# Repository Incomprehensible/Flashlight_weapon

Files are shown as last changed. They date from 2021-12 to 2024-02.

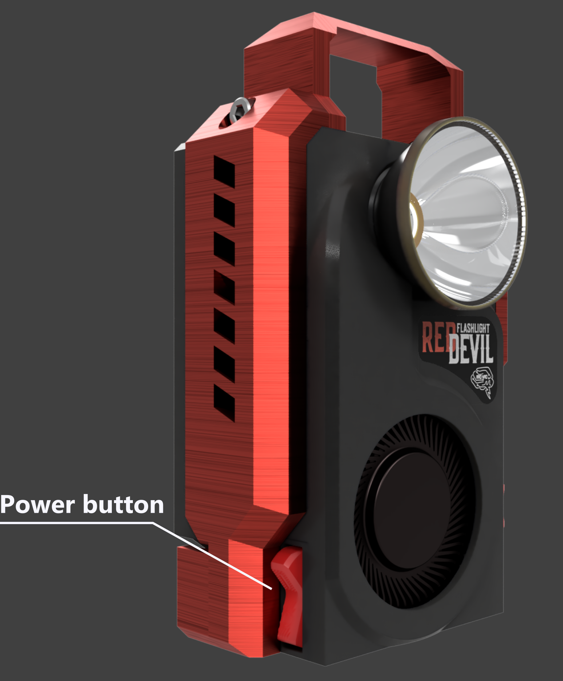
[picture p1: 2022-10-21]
Renders&Graphics/21_NAD_flashlight_2_EDIT_3_explanation.png

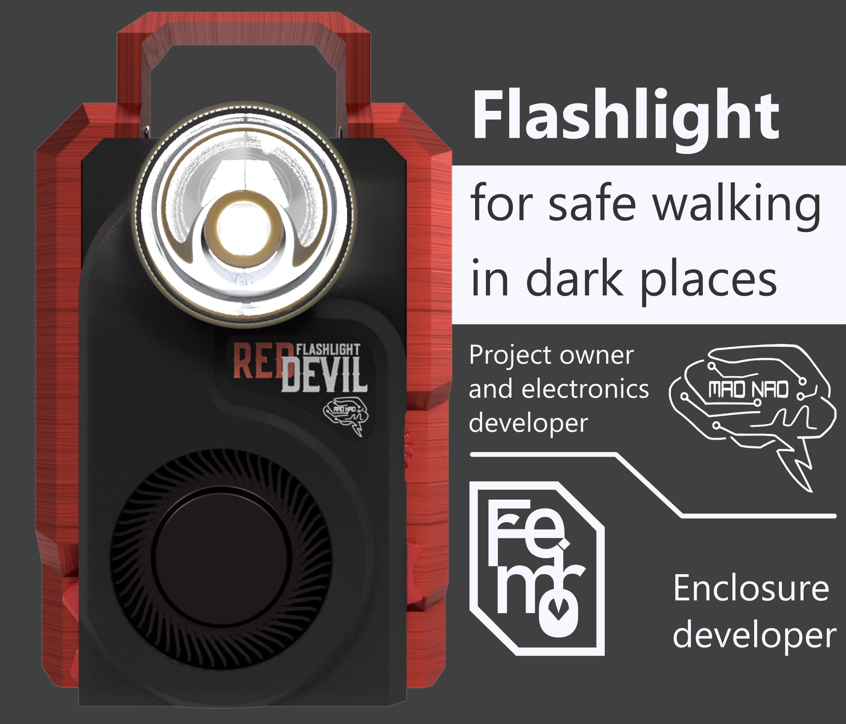
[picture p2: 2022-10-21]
Renders&Graphics/21_NAD_flashlight_2_EDIT_1_explanation.png

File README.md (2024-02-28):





## Flashlight features
__Two operation modes toggled by selector__

 * Normal light: regular use

 * Emergency mode: blinding light attack

__Variable light intensity, changable with a knob__

__Interchangeable lens__

__Mount for action camera accessories__
<br/><br/>
<br/><br/>
<br/><br/>
<br/><br/>
 

### Electrical characteristics
* 12.6V - 10.5V input
* ~4.5A input
* 7V output
* 7.5A output
<br/><br/>
<br/><br/>
<br/><br/>
<br/><br/>
## PCB design

Top             |  Bottom
:-------------------------:|:-------------------------:
  |  
 | 

#### Further improvement in design:
* Add a latching circuit with bistable relay to avoid losing power in emergency mode.
* Add suitable input power filtering.

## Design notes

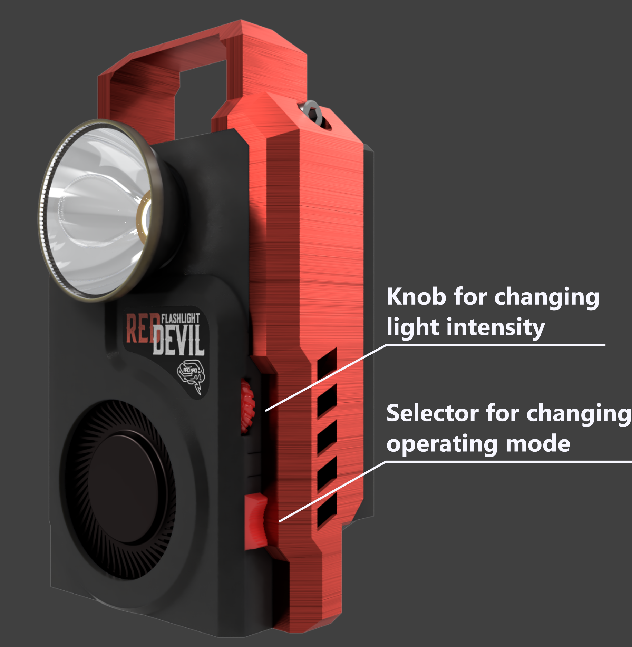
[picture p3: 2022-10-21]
Renders&Graphics/21_NAD_flashlight_2_EDIT_2_explanation.png

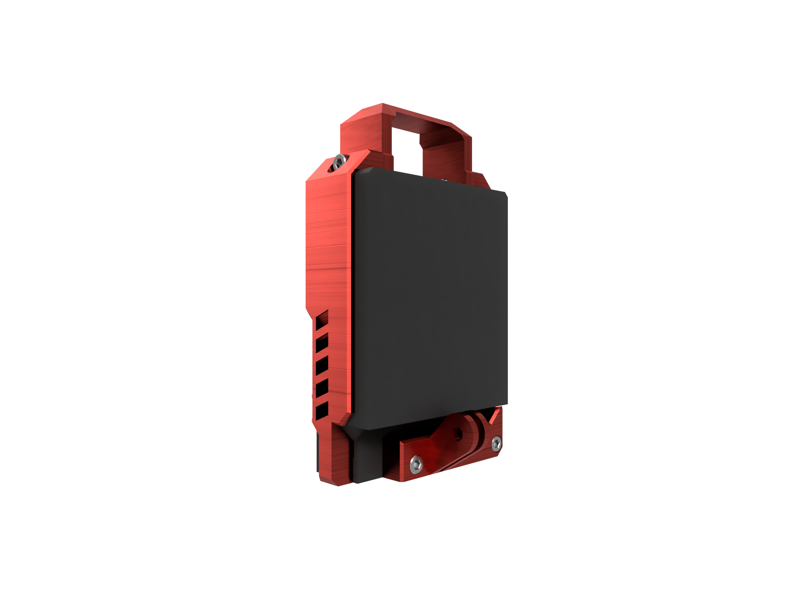
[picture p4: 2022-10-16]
Renders&Graphics/21_NAD_flashlight_front_8.png

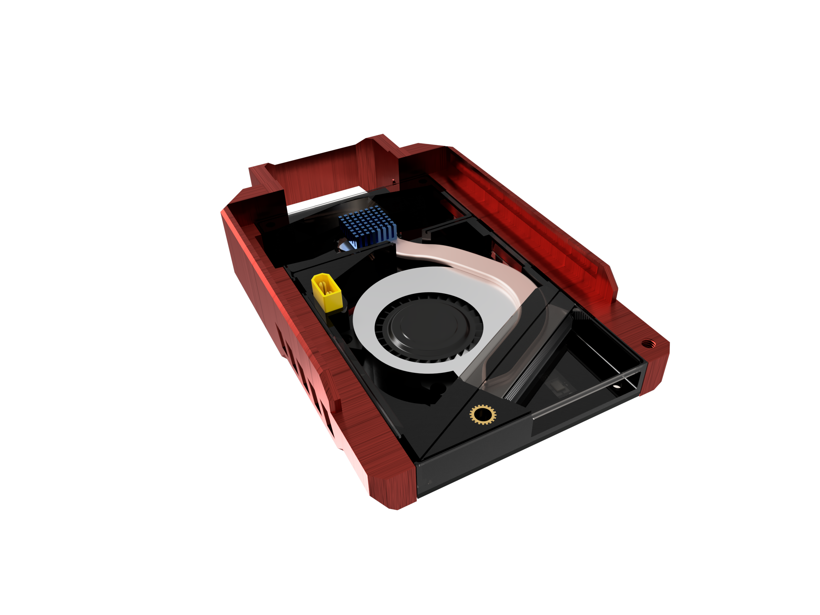
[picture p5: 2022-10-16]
Renders&Graphics/21_NAD_flashlight_front_19.PNG

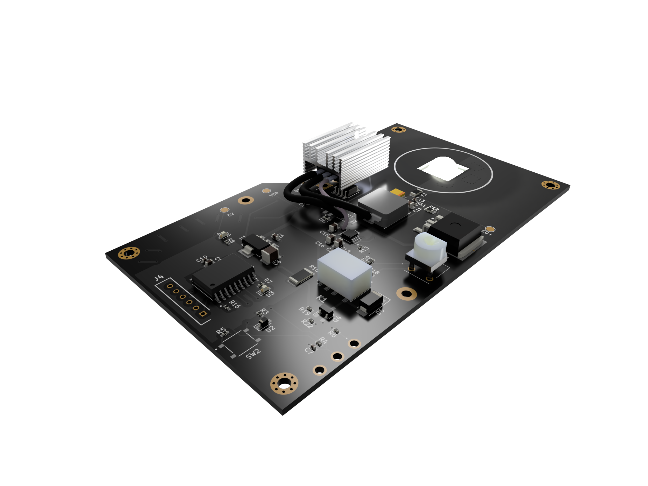
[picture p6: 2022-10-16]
Renders&Graphics/21_NAD_flashlight_front_20.PNG

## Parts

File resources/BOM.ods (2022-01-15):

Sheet: Roster
Flashlight |  |  |  |  |  |  | 2021
TEAM NAD
# | Component | Name | Qua-ty | Link | Price | Datasheet | Notes
1 | Cvin | GRM21BR61E106MA73L | 2 | https://www.chipdip.ru/product0/8001940268 | 130 * 2 | https://search.murata.co.jp/Ceramy/image/img/A01X/G101/ENG/GRM21BR61E106MA73-01.pdf | 10uF 0805
2 | Rt | CRCW040260K4FKED | 1 | https://lcsc.com/product-detail/Chip-Resistor-Surface-Mount_Vishay-Intertech-CRCW040260K4FKED_C844314.html | 25 | https://www.vishay.com/docs/20035/dcrcwe3.pdf | 60.4k 0402
3 | Cvcc | TMK212BJ474KD-T | 1 | https://lcsc.com/product-detail/Multilayer-Ceramic-Capacitors-MLCC-SMD-SMT_Taiyo-Yuden-TMK212BJ474KD-T_C386088.html | 2*20 | https://ru.mouser.com/datasheet/2/396/mlcc02_e-1307760.pdf | 470nF 0805
4 | Cadj | CL05C102JB5NNNC | 1 | https://lcsc.com/product-detail/Multilayer-Ceramic-Capacitors-MLCC-SMD-SMT_Samsung-Electro-Mechanics-CL05C102JB5NNNC_C307441.html | 0.6*50 | https://datasheet.lcsc.com/lcsc/1810310921_Samsung-Electro-Mechanics-CL05C102JB5NNNC_C307441.pdf | 1nF 0402
5 | Radj | CRCW04023K16FKED | 1 | https://www.chipdip.ru/product0/8008399175 | 130 | https://www.vishay.com/docs/20035/dcrcwe3.pdf | 3.16k 0402
 |  | CR0603-FX-3161ELF | 1 | https://lcsc.com/product-detail/Chip-Resistor-Surface-Mount_BOURNS-CR0603-FX-3161ELF_C203516.html | 6 |  | 3.16k 0603
 |  | 0603WAF2941T5E | 1 | https://lcsc.com/product-detail/Chip-Resistor-Surface-Mount_UNI-ROYAL-Uniroyal-Elec-0603WAF2941T5E_C22909.html | 11 |  | 2.94k 0603
6 | Rsns | RL3720WT-R010-F | 1 | https://www.chipdip.ru/product/rl3720wt-r010-f | 92 | https://static.chipdip.ru/lib/677/DOC011677925.pdf | 0.01 1508
 |  | RL3720WT-R010-FNH | 1 | https://lcsc.com/product-detail/Chip-Resistor-Surface-Mount_Cyntec-RL3720WT-R010-FNH_C367339.html | 27 | https://datasheet.lcsc.com/lcsc/1912111437_Cyntec-RL3720WT-R010-FNH_C367339.pdf | 0.01 1W SMD 1508
7 | Q2 PMOS driver | CSD25402Q3A | 1 | https://lcsc.com/product-detail/MOSFETs_Texas-Instruments-CSD25402Q3A_C111356.html | 100 | https://www.ti.com/lit/ds/symlink/csd25402q3a.pdf
8 | D Schottky | MBRB4030T4G | 1 | https://www.chipdip.ru/product/mbrb4030t4g-schottky-diode-40a-30v-sw | 480 | https://static.chipdip.ru/lib/550/DOC012550016.pdf | too expensive
9 | Inductor | IHLP4040DZER2R2M01 | 1 | https://lcsc.com/product-detail/Power-Inductors_Vishay-Intertech-IHLP4040DZER2R2M01_C499483.html | 104 | https://datasheet.lcsc.com/lcsc/2003271205_Vishay-Intertech-IHLP4040DZER2R2M01_C499483.pdf | alternative: IHLP5050CEER2R2M01
10 | Cff | GRM2165C2A202JA01D | 1 | https://lcsc.com/product-detail/Multilayer-Ceramic-Capacitors-MLCC-SMD-SMT_Murata-Electronics-GRM2165C2A202JA01D_C710939.html | 2*20 | https://datasheet.lcsc.com/lcsc/2103161034_Murata-Electronics-GRM2165C2A202JA01D_C710939.pdf | 2nF 0805
11 | Rfb2 | RC0201FR-0710KL | 1 | https://lcsc.com/product-detail/Chip-Resistor-Surface-Mount_YAGEO-RC0201FR-0710KL_C106225.html | 8 | https://datasheet.lcsc.com/lcsc/1811101938_YAGEO-RC0201FR-0710KL_C106225.pdf | 10k 0201
12 | Rfb1 | RT0805BRD072K18L | 1 | https://www.digikey.be/product-detail/en/yageo/RT0805BRD072K18L/13-RT0805BRD072K18LCT-ND/12704381 | 0.3 dollars |  | 2.18k 0805
13 | Cout tantalum | 10TPE47MAZB | 1 | https://lcsc.com/product-detail/Tantalum-Capacitors_PANASONIC-10TPE47MAZB_C147768.html | 45 | https://datasheet.lcsc.com/lcsc/1810120928_PANASONIC-10TPE47MAZB_C147768.pdf | 47uF CASE-B_3528
14 | Rparallel | CR0603F3K00P05Z | 1 | https://lcsc.com/product-detail/Chip-Resistor-Surface-Mount_Ever-Ohms-Tech-CR0603F3K00P05Z_C881244.html | 14 |  | 3k 0603 100mW
 |  | 0603WAF3091T5E | 1 | https://lcsc.com/product-detail/Chip-Resistor-Surface-Mount_UNI-ROYAL-Uniroyal-Elec-0603WAF3091T5E_C22992.html | 10 |  | 3.1k 0603 100mW
 |  | WR06X1501FTL | 1 | https://lcsc.com/product-detail/Chip-Resistor-Surface-Mount_Walsin-Tech-Corp-WR06X1501FTL_C163839.html | 7 |  | 1.5k 0603 100mW
 |  | RTT03102JTP | 1 | https://lcsc.com/product-detail/Chip-Resistor-Surface-Mount_RALEC-RTT03102JTP_C103209.html | 8 |  | 1k 0603 100mW
15 | Rcushion | TyoHM SMF 3W 10R J | 1 | https://lcsc.com/product-detail/Chip-Resistor-Surface-Mount_TyoHM-SMF-3W-10R-J_C395115.html | 3 |  | 10Ω SMD 3W
 |  | TyoHM SMF 3W 100R J | 1 | https://lcsc.com/product-detail/Chip-Resistor-Surface-Mount_TyoHM-SMF-3W-100R-J_C395118.html | 4 |  | 100Ω SMD 3W
16 | Rvariable | VZ067TL1B303 | 1 | https://lcsc.com/product-detail/Variable-Resistors-Potentiometers_HDK-Hokuriku-Elec-Industry-VZ067TL1B303_C145139.html | 33 | https://datasheet.lcsc.com/lcsc/1810170429_HDK-Hokuriku-Elec-Industry-VZ067TL1B303_C145139.pdf | 30k 0.1W
17 | Mode switch | SS-12D06L5 | 1 | https://lcsc.com/product-detail/Slide-Switches_XKB-Connectivity-SS-12D06L5_C319015.html | 22 | https://datasheet.lcsc.com/lcsc/2110151630_XKB-Connectivity-SS-12D06L5_C319015.pdf | SPDT 250V 3A
18 | Relay | HFD4/24-SR | 1 | https://lcsc.com/product-detail/Signal-Relays_HF-Xiamen-Hongfa-Electroacoustic-HFD4-24-SR_C390665.html | 150 | https://datasheet.lcsc.com/lcsc/1912111437_HF-Xiamen-Hongfa-Electroacoustic-HFD4-24-SR_C390665.pdf | SPDT 24V DC 2A non-blocking
19 | MCU | PIC16F716-I/SO | 1 | https://www.chipdip.ru/product/pic16f716-i-so | 56 | https://static.chipdip.ru/lib/046/DOC003046591.pdf | SOIC
20 | DC-DC | AMS1117-5.0 | 1 | https://lcsc.com/product-detail/Linear-Voltage-Regulators-LDO_HGC-Huaguan-Semicon-AMS1117-5-0_C498116.html | 7*5 | https://datasheet.lcsc.com/lcsc/2005291002_HGC-Huaguan-Semicon-AMS1117-5-0_C498116.pdf | 5V SOT223
21 | Crystal | X1E0003410031 | 1 | https://lcsc.com/product-detail/Crystals_Seiko-Epson-X1E0003410031_C725712.html | 35 | https://datasheet.lcsc.com/lcsc/2008192035_Seiko-Epson-X1E0003410031_C725712.pdf | -40℃~+125℃ SMD3225-4P
22 | Power connector | XT60PW-F | 1 | https://www.chipdip.ru/product/xt60pw-f | 320
 |  | XT30PW-F | 1 |  |  |  | bought on aliexpress
23 | Temp sensor | LM60BIM3 | 1 | https://www.chipdip.ru/product0/8002949797 | 280 | https://static.chipdip.ru/lib/053/DOC006053227.pdf | SOT-23
24 | Schottky 12V | 1N5819WS | 1 | https://lcsc.com/product-detail/Schottky-Barrier-Diodes-SBD_Guangdong-Hottech-1N5819WS_C191023.html | 44 | https://datasheet.lcsc.com/lcsc/1810202112_Guangdong-Hottech-1N5819WS_C191023.pdf | 40V SOD-323
25 | Power fuse | 121108 | 1 | https://lcsc.com/product-detail/Fuses_TLC-Electronic-121108_C364828.html | 32 | https://datasheet.lcsc.com/lcsc/1912111437_TLC-Electronic-121108_C364828.pdf | Delay 8A 123mV 24V 10mΩ 1206
 |  | 12T.70000032AG12S1B02 | 1 | https://lcsc.com/product-detail/Fuses_Xucheng-Elec-12T-70000032AG12S1B02_C140481.html | 27 | https://datasheet.lcsc.com/lcsc/1809211025_Xucheng-Elec-12T-70000032AG12S1B02_C140481.pdf | Delay 7A 1206 32V
 |  | 12T.00100024AG12S1B02 | 1 | https://lcsc.com/product-detail/Fuses_Xucheng-Elec-12T-00100024AG12S1B02_C140482.html | 32 | https://datasheet.lcsc.com/lcsc/1809211025_Xucheng-Elec-12T-00100024AG12S1B02_C140482.pdf | Delay 10A 1206
 |  | 0458010.DR | 1 | https://lcsc.com/product-detail/Fuses_Littelfuse-0458010-DR_C187564.html | 25 | https://datasheet.lcsc.com/lcsc/1810111822_Littelfuse-0458010-DR_C187564.pdf | Fast 10A 1206
26 | LED fuse | 1211012 | 1 | https://lcsc.com/product-detail/Fuses_TLC-Electronic-1211012_C364830.html | 20 | https://datasheet.lcsc.com/lcsc/1912111437_TLC-Electronic-1211012_C364830.pdf | Delay 12A 24V 5mΩ 1206
 |  | 1211015 | 1 | https://lcsc.com/product-detail/Fuses_TLC-Electronic-1211015_C364831.html | 31 |  | Delay 15A 3.5mΩ 1206
 |  | 0501020.WR | 1 | https://lcsc.com/product-detail/Fuses_Littelfuse-0501020-WR_C371157.html | 17 | https://datasheet.lcsc.com/lcsc/1912111437_Littelfuse-0501020-WR_C371157.pdf | Fast 20A 32V 58.88mV 1206
27 | TVS D | SDC15.TCT | 1 | https://lcsc.com/product-detail/span-style-background-color-ff0-TVS-span_SEMTECH-SDC15-TCT_C441849.html | 22 | https://datasheet.lcsc.com/lcsc/2004021403_SEMTECH-SDC15-TCT_C441849.pdf | 10A BR=14.3V 12.8V 7Inch
28 | Q1 PMOS Vin | YJS4407A | 1 | https://lcsc.com/product-detail/MOSFETs_Yangzhou-Yangjie-Elec-Tech-YJS4407A_C919398.html | 47 | https://www.21yangjie.com/ggs/mosfet/zdymosfet/YJS4407A.pdf | P-channel 30V 12A 10.5mΩ
29 | ICSP header | B6B-EH-A | 1 | https://www.chipdip.ru/product/b6b-eh-a | 37 | https://static.chipdip.ru/lib/060/DOC000060471.pdf | 6 pin JST
30 | TH2 NTC | NCP18XW223J03RB | 1 | https://lcsc.com/product-detail/NTC-Thermistors_Murata-Electronics-NCP18XW223J03RB_C86144.html | 44 | https://datasheet.lcsc.com/lcsc/1810311126_Murata-Electronics-NCP18XW223J03RB_C86144.pdf | 22kΩ 100mW 0603
 |  | ERTJ1VR333J | 1 | https://lcsc.com/product-detail/NTC-Thermistors_PANASONIC-ERTJ1VR333J_C153017.html | 25 | https://lcsc.com/product-detail/NTC-Thermistors_PANASONIC-ERTJ1VR333J_C153017.html | 33kΩ 100mW 0603
31 | Q3 NMOS | YJL2302B | 1 | https://lcsc.com/product-detail/MOSFETs_Yangzhou-Yangjie-Elec-Tech-YJL2302B_C699316.html | 35 | https://datasheet.lcsc.com/lcsc/2007231239_Yangzhou-Yangjie-Elec-Tech-YJL2302B_C699316.pdf | 20V 3A SOT-23-3L SOT-23-3L
32 | Q4 NMOS | YJL2302B | 1 | https://lcsc.com/product-detail/MOSFETs_Yangzhou-Yangjie-Elec-Tech-YJL2302B_C699316.html |  | https://datasheet.lcsc.com/lcsc/2007231239_Yangzhou-Yangjie-Elec-Tech-YJL2302B_C699316.pdf | SOT-23-3L
33 | Flyback D | HD20G | 1 | https://lcsc.com/product-detail/Diodes-General-Purpose_High-span-style-background-color-ff0-Diode-span-HD20G_C466497.html | 3*10 | https://datasheet.lcsc.com/lcsc/1912111437_High-Diode-HD20G_C466497.pdf | 2kV 1A SMAG

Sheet: Schedule
Team Name |  |  |  |  |  | 2016
SCHEDULE
Date | Day | Time | Location | Opponent | Home/Away | Notes | Score
Sep 4 | Monday | 1:00 PM | Park A - Field #1 | Team 2 | Home |  | 1-1
 | Saturday
 | Saturday
 | Saturday
 | Saturday
 | Saturday
 | Saturday
 | Saturday
 | Saturday
 | Saturday
 | Saturday
 | Saturday
 | Saturday
 | Saturday
 | Saturday

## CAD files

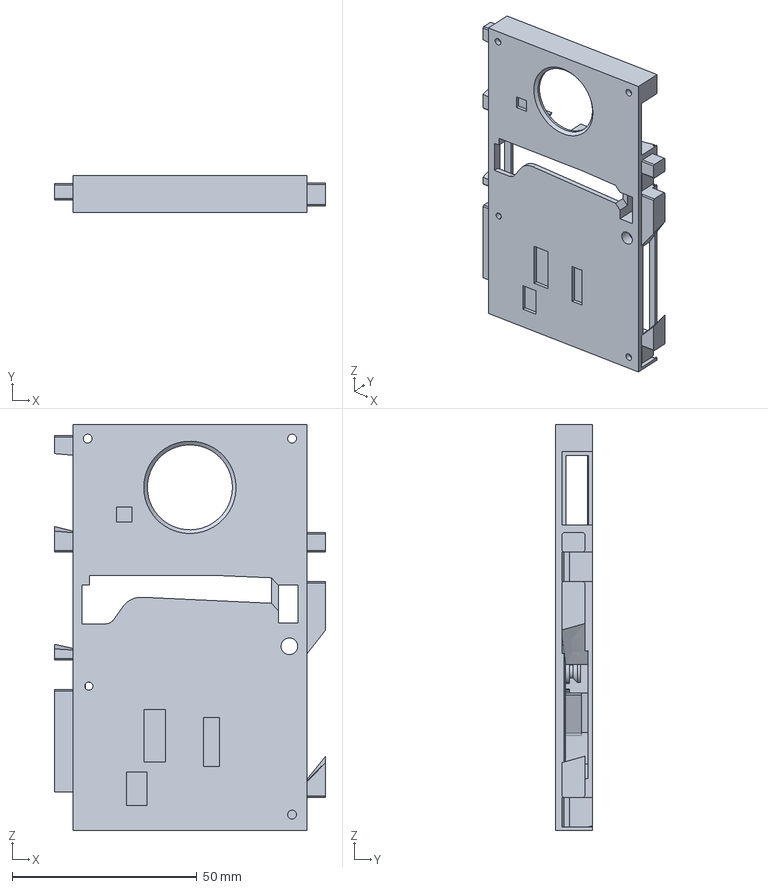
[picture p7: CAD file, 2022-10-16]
3D_models/Files_for_production/2LVL_base_Heat-ResistantPhotopolymer.step
73.5 x 10.1 x 110.0 mm

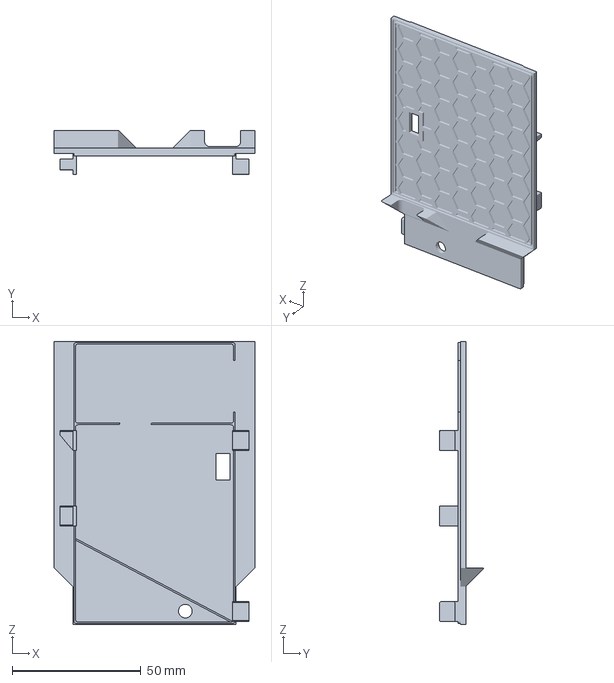
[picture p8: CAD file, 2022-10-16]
3D_models/Files_for_prototype/2LVL_face_PETG.3mf
78.0 x 17.3 x 110.0 mm

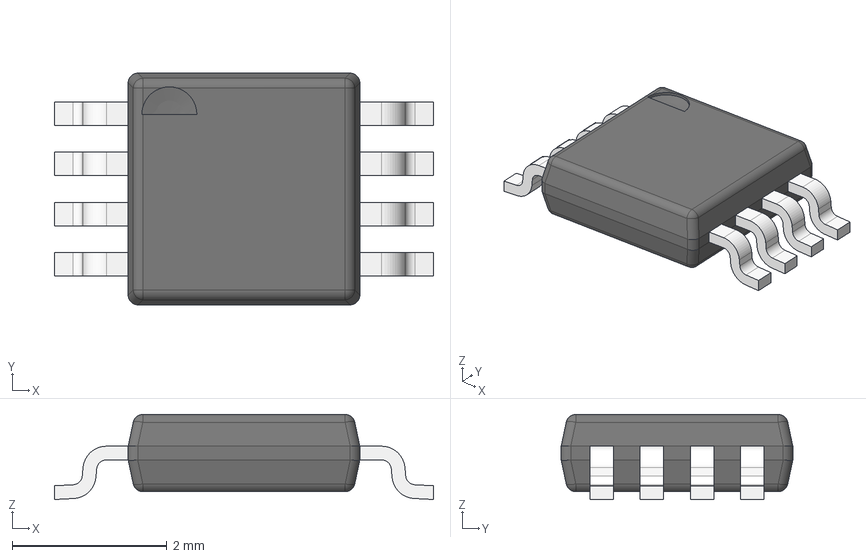
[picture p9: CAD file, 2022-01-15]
KiCad/3D/DGK0008A.stp
4.90 x 3.00 x 1.10 mm
BODY_MUA08A
LEAD_MUA08A x 8

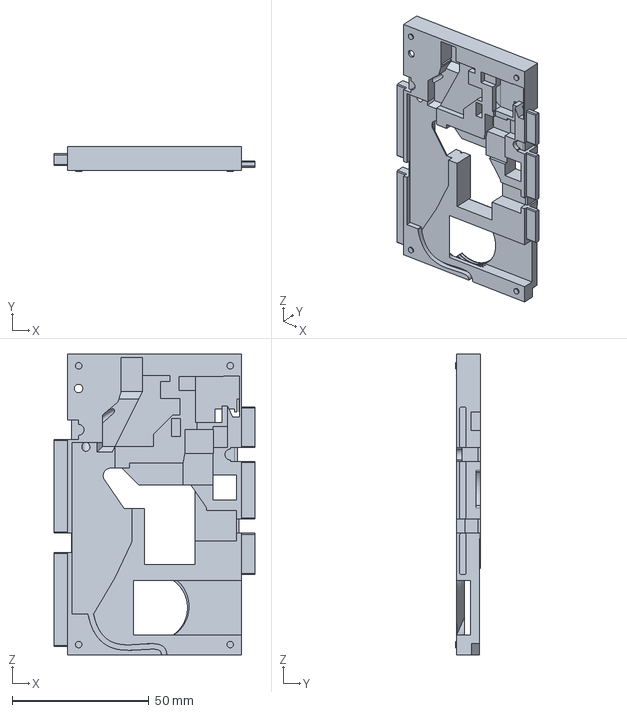
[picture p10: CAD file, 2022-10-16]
3D_models/Files_for_production/1LVL_base_NYLON_PA12.step
73.3 x 9.30 x 110.0 mm

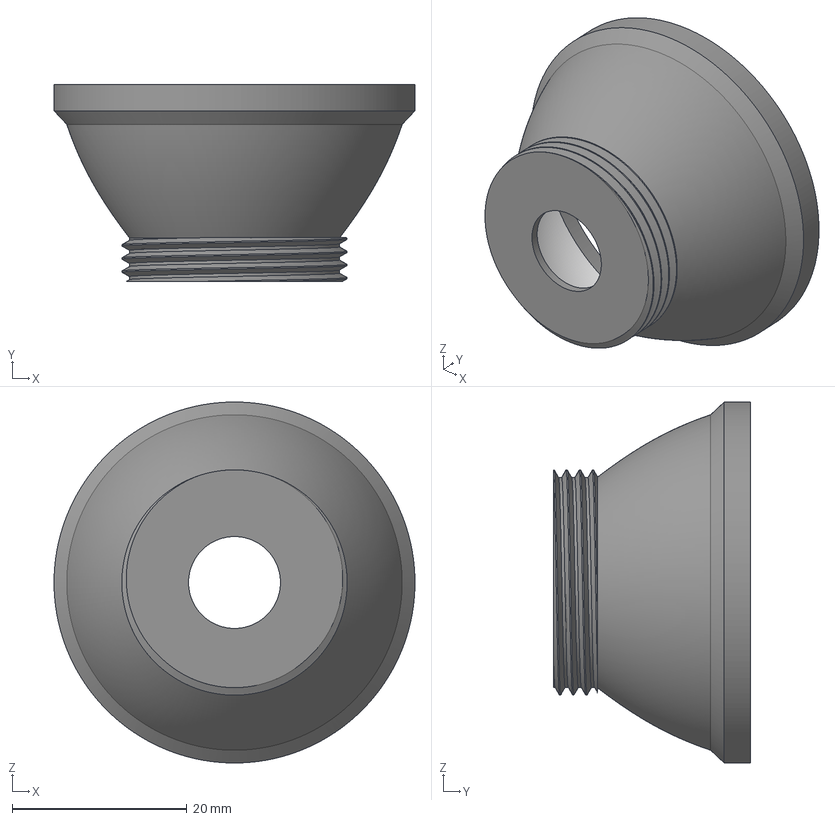
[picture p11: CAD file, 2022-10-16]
3D_models/Files_for_prototype/BigLens_body_PETG.3mf
41.3 x 22.5 x 41.3 mm

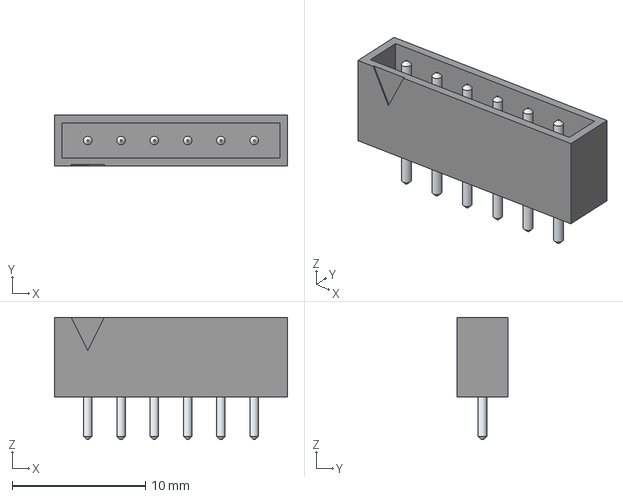
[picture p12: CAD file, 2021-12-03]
KiCad/3D/B6B-EH-A__LF___SN_.stp
17.5 x 3.80 x 9.20 mm
LeadsArray

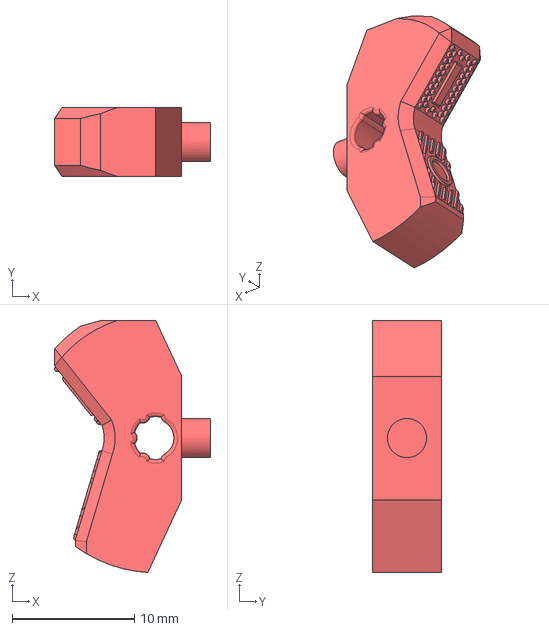
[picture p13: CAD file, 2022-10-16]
3D_models/Files_for_production/Switch_cap_ANY.step
12.7 x 5.60 x 20.6 mm

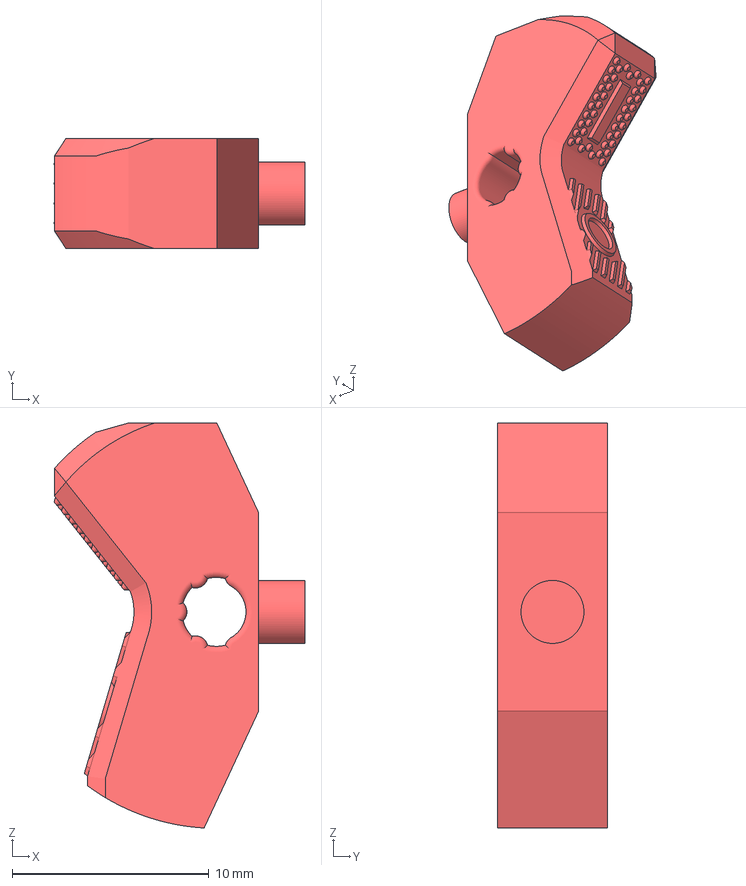
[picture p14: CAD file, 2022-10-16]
3D_models/Files_for_prototype/Switch_cap_ANY.3mf
12.7 x 5.60 x 20.6 mm

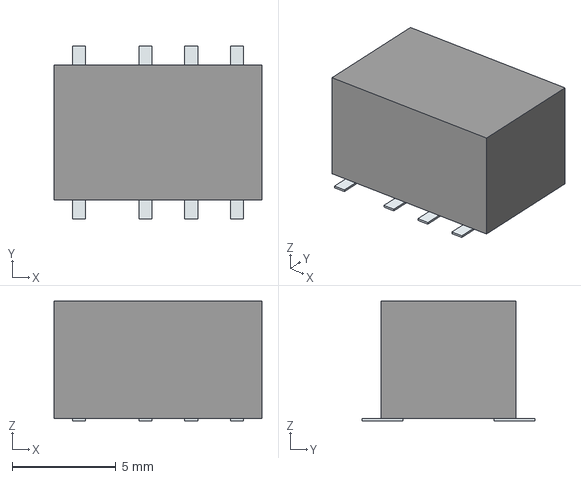
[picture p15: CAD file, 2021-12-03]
KiCad/3D/HFD4_024-S.stp
10.0 x 8.34 x 5.75 mm
Pins

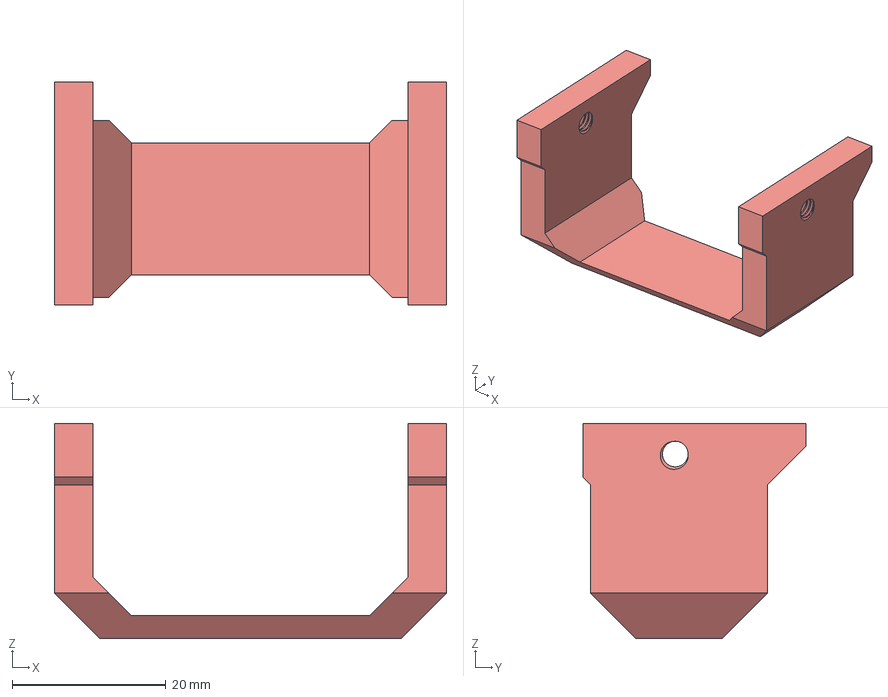
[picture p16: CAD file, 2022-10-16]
3D_models/Files_for_production/Frame_up_Aluminum.step
50.9 x 29.0 x 28.0 mm

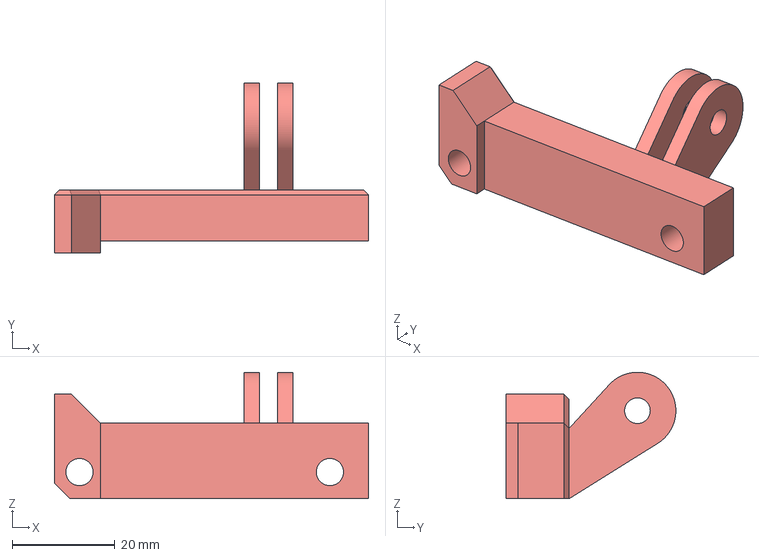
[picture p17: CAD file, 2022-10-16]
3D_models/Files_for_prototype/Frame_down_PETG.3mf
61.2 x 33.1 x 24.7 mm

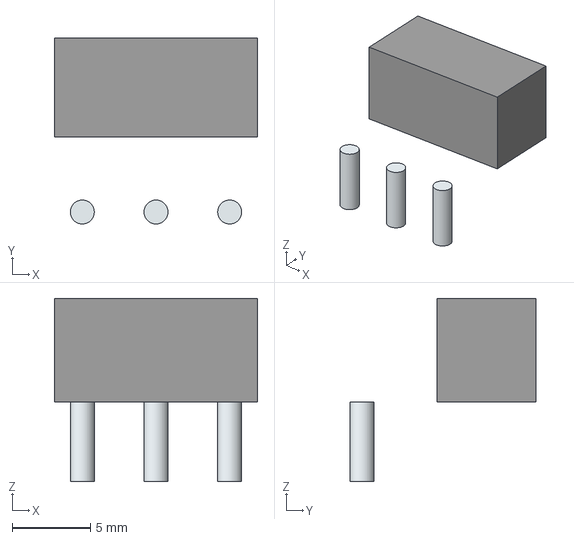
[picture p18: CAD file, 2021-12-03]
KiCad/3D/SS-12D06L5.stp
13.0 x 11.9 x 11.7 mm
Leads x 3

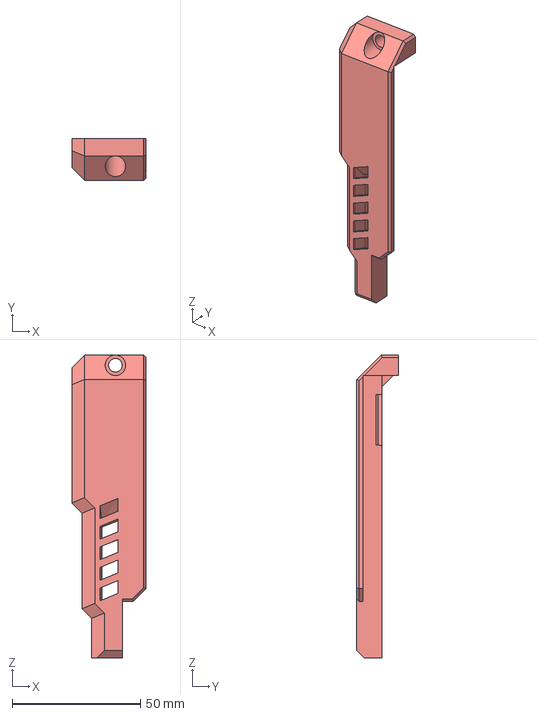
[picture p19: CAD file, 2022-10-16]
3D_models/Files_for_production/Frame_right_Aluminum.step
29.0 x 16.3 x 118.0 mm

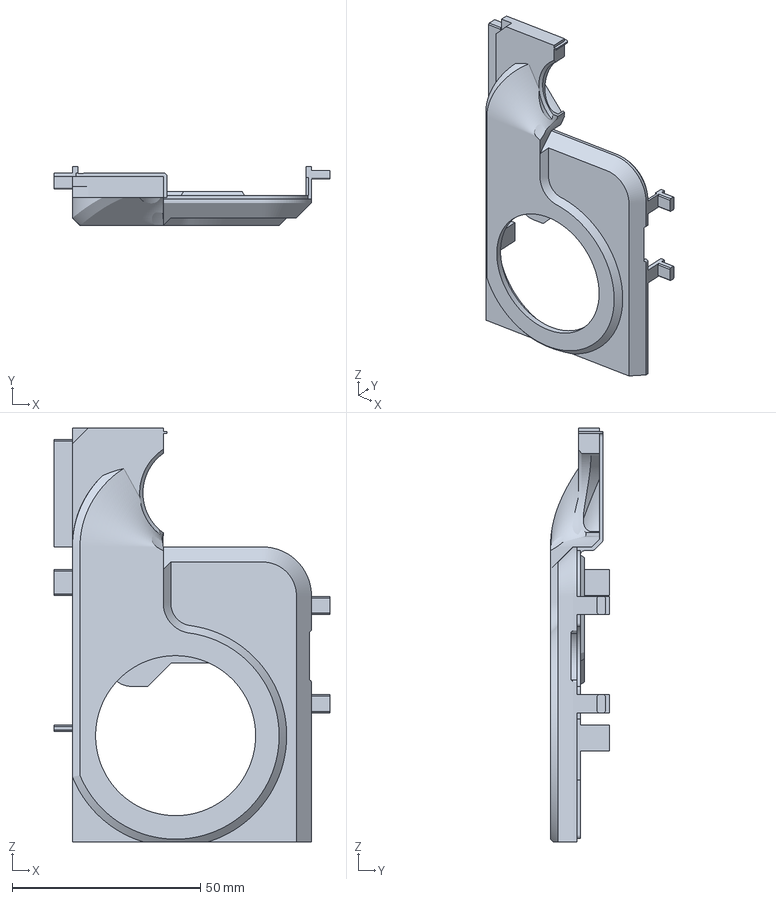
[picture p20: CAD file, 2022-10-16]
3D_models/Files_for_prototype/1LVL_front_PETG.3mf
73.3 x 15.7 x 110.0 mm

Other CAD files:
KiCad/3D/XT30PW-F.stp
3D_models/Files_for_production/2LVL_face_NYLON_PA12.step
3D_models/Files_for_prototype/Selector_cap_ANY.3mf
KiCad/3D/IHLP4040DZER2R2M01.stp
3D_models/Files_for_production/1LVL_front_NYLON_PA12.step
3D_models/Files_for_production/2LVL_battery_NYLON_PA12.step
3D_models/Files_for_production/BigLens_body_Aluminum.step
3D_models/Files_for_production/Frame_down_Aluminum.step
3D_models/Files_for_production/Frame_left_Aluminum.step
3D_models/Files_for_production/Knob_ANY.step
3D_models/Files_for_production/Selector_cap_ANY.step
3D_models/Files_for_prototype/1LVL_base_PETG.3mf
3D_models/Files_for_prototype/2LVL_base_Photopolymer.3mf
3D_models/Files_for_prototype/2LVL_battery_PETG.3mf
3D_models/Files_for_prototype/Frame_left_PETG.3mf
3D_models/Files_for_prototype/Frame_right_PETG.3mf
3D_models/Files_for_prototype/Frame_up_PETG.3mf
3D_models/Files_for_prototype/Knob_ANY.3mf
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

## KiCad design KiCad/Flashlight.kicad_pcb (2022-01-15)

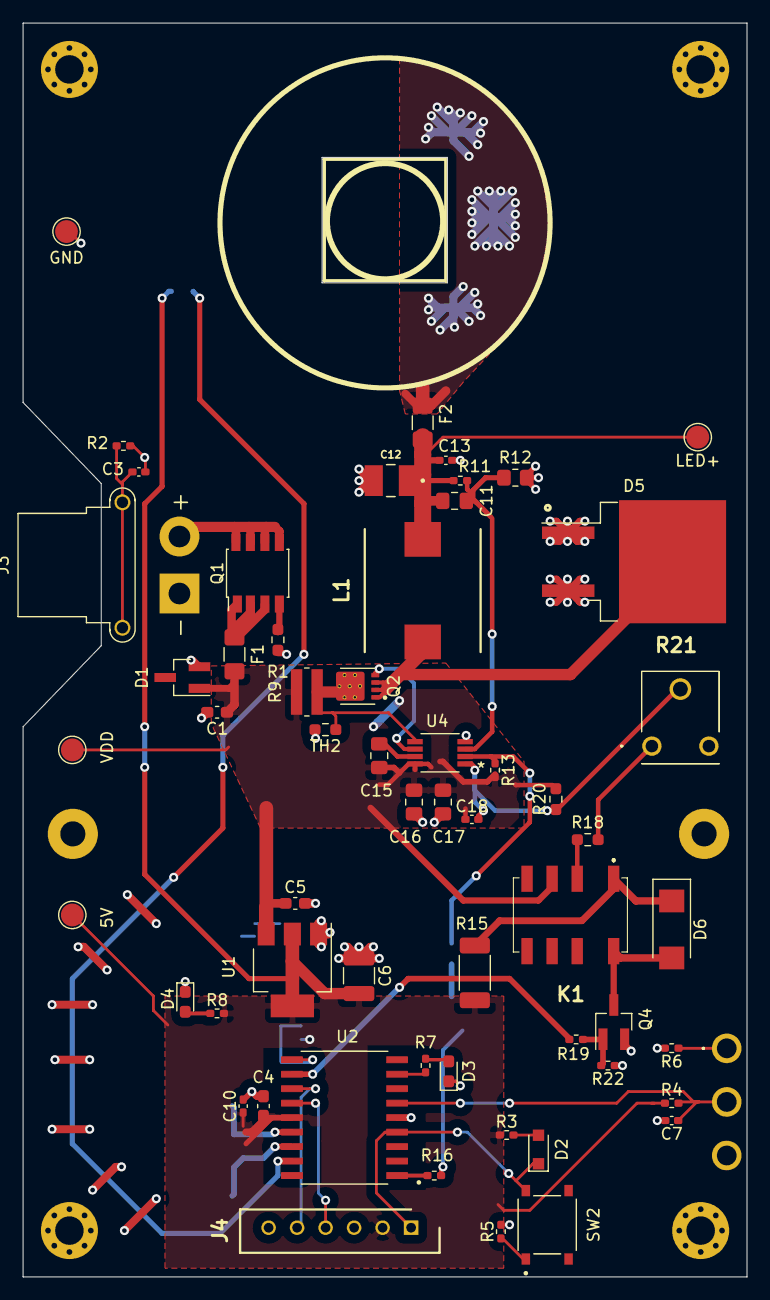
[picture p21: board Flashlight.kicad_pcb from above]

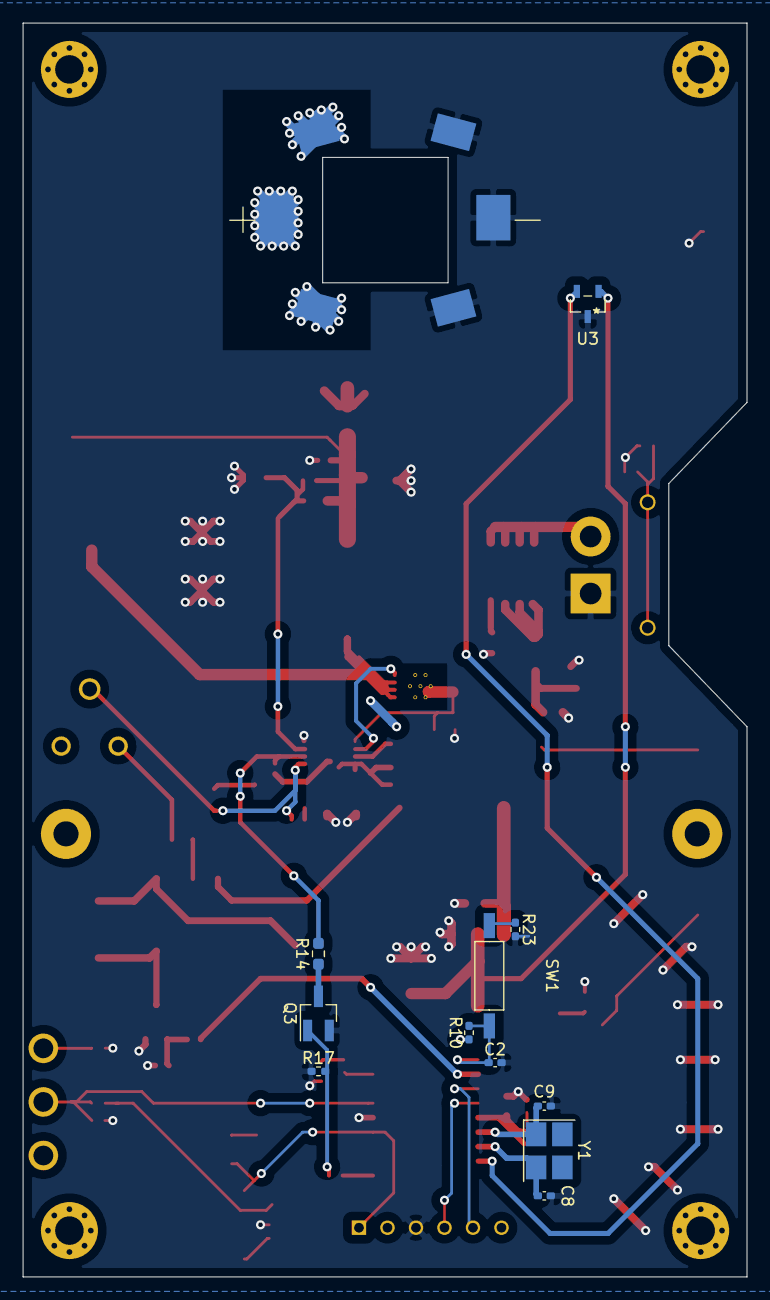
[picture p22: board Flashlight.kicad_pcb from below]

Board: 2 copper layers, 63.5 x 110.0 mm, 76 parts (12 on the bottom side), 40 nets.

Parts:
C1, C4, C5: C; C_0603_1608Metric_Pad1.08x0.95mm_HandSolder
C2, C7, C8, C9: C; C_0402_1005Metric_Pad0.74x0.62mm_HandSolder
C3: C_Small; C_0402_1005Metric_Pad0.74x0.62mm_HandSolder
C6: CP; C_1210_3225Metric_Pad1.33x2.70mm_HandSolder
C10, C13: C_reserve; C_0402_1005Metric_Pad0.74x0.62mm_HandSolder
C11: Cff; C_0805_2012Metric_Pad1.18x1.45mm_HandSolder
C12: Cout; CAP_10TPE47MAZB
C15: Cvcc; C_0805_2012Metric_Pad1.18x1.45mm_HandSolder
C16, C17: Cin; C_0805_2012Metric_Pad1.18x1.45mm_HandSolder
C18: Cadj; C_0402_1005Metric_Pad0.74x0.62mm_HandSolder
D1: D_TVS; SOT-23_Handsoldering
D2: D_Schottky; D_SOD-323_HandSoldering
D3: BLINK_TEST; LED_0603_1608Metric_Pad1.05x0.95mm_HandSolder
D4: PWR_STATUS; LED_0603_1608Metric_Pad1.05x0.95mm_HandSolder
D5: Driver_Schottky; TO-263-2
D6: D_flyback; D_SMAG
F1: Fuse_PWR; Fuse_1206_3216Metric_Pad1.42x1.75mm_HandSolder
F2: Fuse_LED; Fuse_1206_3216Metric_Pad1.42x1.75mm_HandSolder
H1, H2, H3, H4: MountingHole; MountingHole_2.5mm_Pad_Via
H5, H6: BMS_mnt; MountingHole_2.2mm_M2_Pad
J2: XHP90
J3: XT30PW-F; AMASS_XT30PW-F
J4: ICSP 1x6; B6B-EH-A
K1: HFD4-24-SR; HFD4024S
L1: L; IHLP4040DZER2R2M01
Q1: PMOS_Vin; YJS4407A
Q2: CSD25402Q3A; TRANS_CSD25402Q3A
Q3, Q4: Q_NMOS_GSD; SOT-23_Handsoldering
R1, R14: R; R_0603_1608Metric_Pad0.98x0.95mm_HandSolder
R2, R3: 10k; R_0402_1005Metric_Pad0.72x0.64mm_HandSolder
R4, R5, R6, R7, R8, R10, R16, R19, R22, R23: R; R_0402_1005Metric_Pad0.72x0.64mm_HandSolder
R9: Rsns; R_1508_Wide
R11: Rfb2; R_0402_1005Metric_Pad0.72x0.64mm_HandSolder
R12: Rfb1; R_0805_2012Metric_Pad1.20x1.40mm_HandSolder
R13: Rt; R_0402_1005Metric_Pad0.72x0.64mm_HandSolder
R15: R_cushion; TyoHM-SMF-3W
R17: Rterm; R_0402_1005Metric_Pad0.72x0.64mm_HandSolder
R18: Rpar; R_0603_1608Metric_Pad0.98x0.95mm_HandSolder
R20: Radj; R_0603_1608Metric_Pad0.98x0.95mm_HandSolder
R21: R_Variable; VZ067TL1B
S1: SS-12D06L5; SS12D06L5
SW1: SW_SPST; DSIC01LSGET
SW2: SW_Push; SW_TS-1187A-B-A-B
TH2: Thermistor_NTC; R_0603_1608Metric_Pad0.98x0.95mm_HandSolder
TP1: 5V; TestPoint_Pad_D2.0mm
TP2: VDD; TestPoint_Pad_D2.0mm
TP3: GND; TestPoint_Pad_D2.0mm
TP4: LED+; TestPoint_Pad_D2.0mm
U1: AMS1117-5.0; SOT-223-3_TabPin2
U2: PIC16F716-ISO; SOIC127P1030X265-18N
U3: LM60BIM3
U4: LM25085MM_NOPB; LM25085MM&slash_NOPB
Y1: Crystal; Crystal_SMD_3225-4Pin_3.2x2.5mm_HandSoldering

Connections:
+5V: C4.2, C6.1, C10.1, J4.2, R3.1, R4.1, R8.2, R10.1, R15.2, TP1.1, U1.2, U2.14, U3.1
ADJ: C18.2, R20.1, R21.2, U4.1
ANALOG_TEMP: U2.17, U3.2
CLK: J4.5, U2.12
DATA: J4.4, U2.13
ENABLE_DCDC: C2.1, R10.2, SW1.2, U2.10
FB: C11.2, R11.1, R12.2, U4.3
ISEN: Q2.9, Q2.9_1, Q2.9_2, Q2.9_3, Q2.9_4, Q2.9_5, Q2.9_6, Q2.9_7, R9.1, TH2.1, U4.5
LED_GND: C1.2, C2.2, C3.2, C4.1, C5.2, C6.2, C7.2, C8.1, C9.1, C10.2, C12.2, C13.2, C16.2, C17.2, D1.2, D3.1, D4.1, D5.1, D5.3, J2.1, J3.1, J4.3, Q3.2, Q4.2, R1.1, R2.2, R5.2, R6.2, R12.1, R17.1, R22.1, R23.2, TH2.2, TP3.1, U1.1, U2.5, U3.3, U4.4
LED_VDD: C11.1, C12.1, C13.1, F2.2, L1.2, R11.2, TP4.1
MODE: C7.1, R4.2, S1.2, U2.6
unnamed: C3.1, J3.3, J3.4, R2.1
unnamed: C8.2, U2.16, Y1.2
unnamed: C9.2, U2.15, Y1.1
unnamed: C15.1, U4.7
unnamed: D2.2, R3.2
unnamed: D3.2, R7.2
unnamed: D4.2, R8.1
unnamed: D5.4, L1.1, Q2.1, Q2.2, Q2.3
unnamed: D6.1, K1.1, R15.1
unnamed: D6.2, K1.8, Q4.3
unnamed: F1.2, Q1.1, Q1.2, Q1.3
unnamed: F2.1, J2.2
unnamed: K1.2, R18.2
unnamed: Q1.4, R1.2
unnamed: Q2.4, U4.6
unnamed: Q3.1, R16.1, R17.2
unnamed: Q3.3, R14.1
unnamed: Q4.1, R19.2, R22.2
unnamed: R5.1, SW2.1
unnamed: R6.1, S1.1
unnamed: R7.1, U2.8
unnamed: R18.1, R21.1
unnamed: R23.1, SW1.1
RELAY: R19.1, U2.11
RT: R13.1, R14.2, U4.2
SHUTDOWN: R16.2, U2.1
VIN: C1.1, C5.1, C15.2, C16.1, C17.1, C18.1, D1.1, F1.1, K1.3, R9.2, R13.2, R20.2, TP2.1, U1.3, U4.8
VPP\RST: D2.1, J4.1, SW2.2, U2.4
VXT: J3.2, Q1.5, Q1.6, Q1.7, Q1.8

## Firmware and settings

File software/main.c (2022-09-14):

/*
 * File:   main.c
 * Author: nad
 *
 * Created on 11 June 2022, 02:08
 */

#define _XTAL_FREQ 8000000

#pragma config FOSC = HS // Oscillator Selection bits (HS oscillator)
#pragma config WDTE = ON // Watchdog Timer Enable bit (WDT enabled)
#pragma config PWRTE = OFF // Power-up Timer Enable bit (PWRT disabled)
#pragma config BOREN = ON // Brown-out Reset Enable bit (BOR enabled)
#pragma config CP = OFF // Flash Program Memory Code Protection bit (Code protection off)

#include <xc.h>

void enter_strobe_mode()
{
    RB5 = 1;
    for (int i=0; i < 10; ++i)
    {
        //RB5 = 0;
        RA2 = 0;
        __delay_ms(400);
        RA2 = 1;
//        RB5 = 1;
        __delay_ms(400);
    }
    RA2 = 0;
}

void init_default_setts()
{
    RA2 = 0; // no shutdown
    RB5 = 0; // normal mode
    RB2 = 0; // LED off
}

void init_ADC()
{
//  Configure I/O pins as analog input(s) and configure ADC reference
    ADCON1bits.PCFG = 0b100;
//  Configure clock
    ADCON0bits.ADCS = 0b11;
//  Configure ADC registers to choose an analog pin
    ADCON0bits.CHS = 0b000;
//  Configure ADC registers to enable the ADC
    ADCON0bits.ADON = 1;    
}

void read_temp()
{
    volatile unsigned int result = 0;
    // Invoke a reading
    ADCON0bits.GO = 1;
    
    while (ADCON0bits.GO == 1);
    result = ADRES;
    
    if (result >= 38) {
        RA2 = 1; // shutdown 
        //RB2 = 1; // LED ON
    }
//    else if (result >= 30) { // 25
//        //RA2 = 1; // shutdown
//        RB2 = 0; // LED OFF
//    }
    else
    {
        if (RB4 != 0)
            RA2 = 0; // NO shutdown
        //RB2 = 0; // LED OFF
    }
}

void main(void) {
    /* setting pin RE0 as output (LED) */
    TRISBbits.TRISB0 = 1; // mode input
    TRISBbits.TRISB4 = 1; // enable DCDC input

    TRISBbits.TRISB2 = 0; // LED DBG output
    TRISBbits.TRISB5 = 0; // High power mode output
    TRISAbits.TRISA2 = 0; // Shutdown mode output
    
    init_ADC();
    
    init_default_setts();

    while (1)
    {
        if (RB0 == 1)
            enter_strobe_mode();
        else
            RB5 = 0;
//        if (RB4 == 0) // shutdown
//            RA2 = 1;
//        else
//            RA2 = 0;
        read_temp();
    }
    return;
}

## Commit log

2021-11-05 Initial schematics.
    [Flashlight.sch, PIC16F716-I_SO.step, RT_versions.sch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]
2021-11-05 Removed screw terminal, power input selection and ferrite bead filter.
    [Flashlight.sch]
2021-12-03 Latest schematics, all footprints except LED.
    [10TPE47MAZB.step, B6B-EH-A__LF___SN_.stp, CSD25402Q3A.step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]
2022-01-15 Finished routing the first version of a PCB. WSON is out of stock so new driver was used.
    [BOM.ods, DGK0008A.stp, Flashlight.kicad_pcb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]
2022-10-14 Add 3d models
    Added Fusion 360 archive project, step production files for order in factory, 3mf files for self-made on 3d printers.
    [1LVL_base_NYLON_PA12.step, 1LVL_base_PETG.3mf, 1LVL_front_NYLON_PA12.step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]
